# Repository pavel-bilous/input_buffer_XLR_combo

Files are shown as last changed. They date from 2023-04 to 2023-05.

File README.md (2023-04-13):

# Input buffer for amplifier with balanced inputs

This buffer serves as an impedance matching and is implemented on the board that allows for balanced XLR inputs for two channels.

## PCB rendered in 3d:
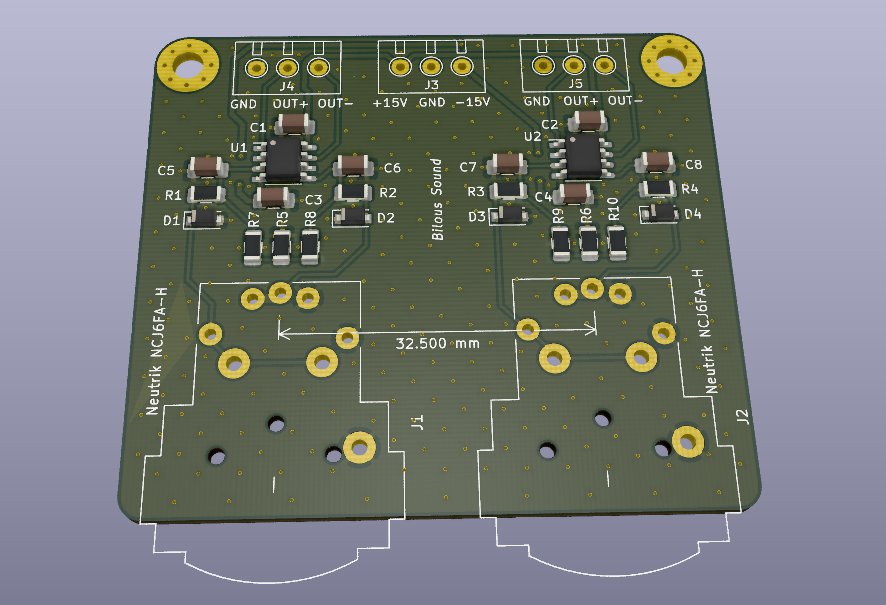
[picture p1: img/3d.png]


## Schematics:

Inputs are ESD protected with bidirectional TVS diodes. Not required, but nice to have. 

Opamps can be NE5532 or LM4562 or any other with good unity gain stability. 

Input XLR connectors are Neutrik NCJ6FA-H.

Capacitors for input low pass filters are C0G or NP0 type. Decoupling capacitors are X7R 100nF or higher (1uF - 10uF will work great).

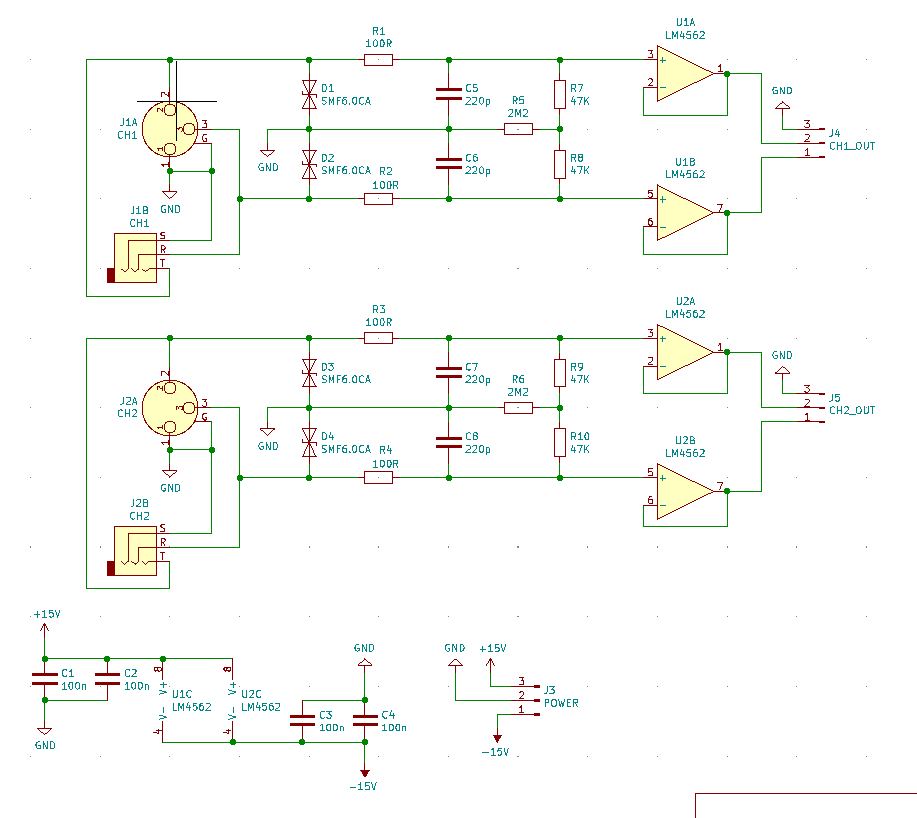
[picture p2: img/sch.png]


## PCB layout:

Bottom layer is GND. Top layer is signal + power and GND poured in between. Stiching vias are then applied to connect bottom and top GND planes to ensure those are as close to 0 as possible.

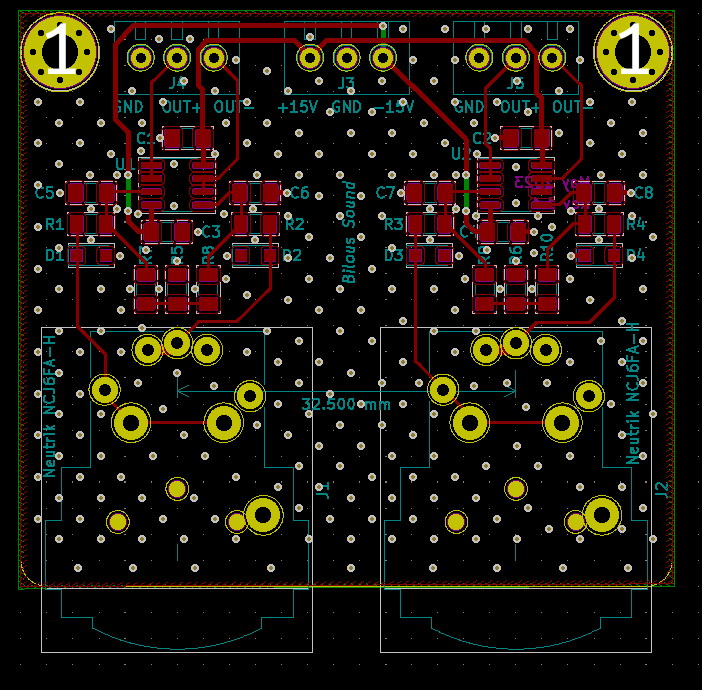
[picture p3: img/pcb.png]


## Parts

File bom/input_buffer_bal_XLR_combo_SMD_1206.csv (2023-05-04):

Id | Designator | Package | Quantity | Designation | Supplier and ref
1 | C8,C7,C6,C5 | C_1206_3216Metric_Pad1.42x1.75mm_HandSolder | 4 | 220p
2 | C4,C3,C2,C1 | C_1206_3216Metric_Pad1.42x1.75mm_HandSolder | 4 | 100n
3 | J1 | Jack_XLR-6.35mm_Neutrik_NCJ6FA-H-0_Horizontal | 1 | CH1
4 | J2 | Jack_XLR-6.35mm_Neutrik_NCJ6FA-H-0_Horizontal | 1 | CH2
5 | D4,D3,D2,D1 | D_SOD-123F | 4 | SMF6.0CA
6 | U2,U1 | SOIC-8_3.9x4.9mm_P1.27mm | 2 | LM4562
7 | R10,R9,R8,R7 | R_1206_3216Metric | 4 | 47K
8 | R6,R5 | R_1206_3216Metric | 2 | 2M2
9 | R4,R3,R2,R1 | R_1206_3216Metric | 4 | 100R
10 | H2,H1 | MountingHole_3.5mm_Pad_Via | 2 | MountingHole
11 | J5 | TerminalBlock_ Amphenol_01_03_P3.50mm | 1 | CH2_OUT
12 | J4 | TerminalBlock_ Amphenol_01_03_P3.50mm | 1 | CH1_OUT
13 | J3 | TerminalBlock_ Amphenol_01_03_P3.50mm | 1 | POWER

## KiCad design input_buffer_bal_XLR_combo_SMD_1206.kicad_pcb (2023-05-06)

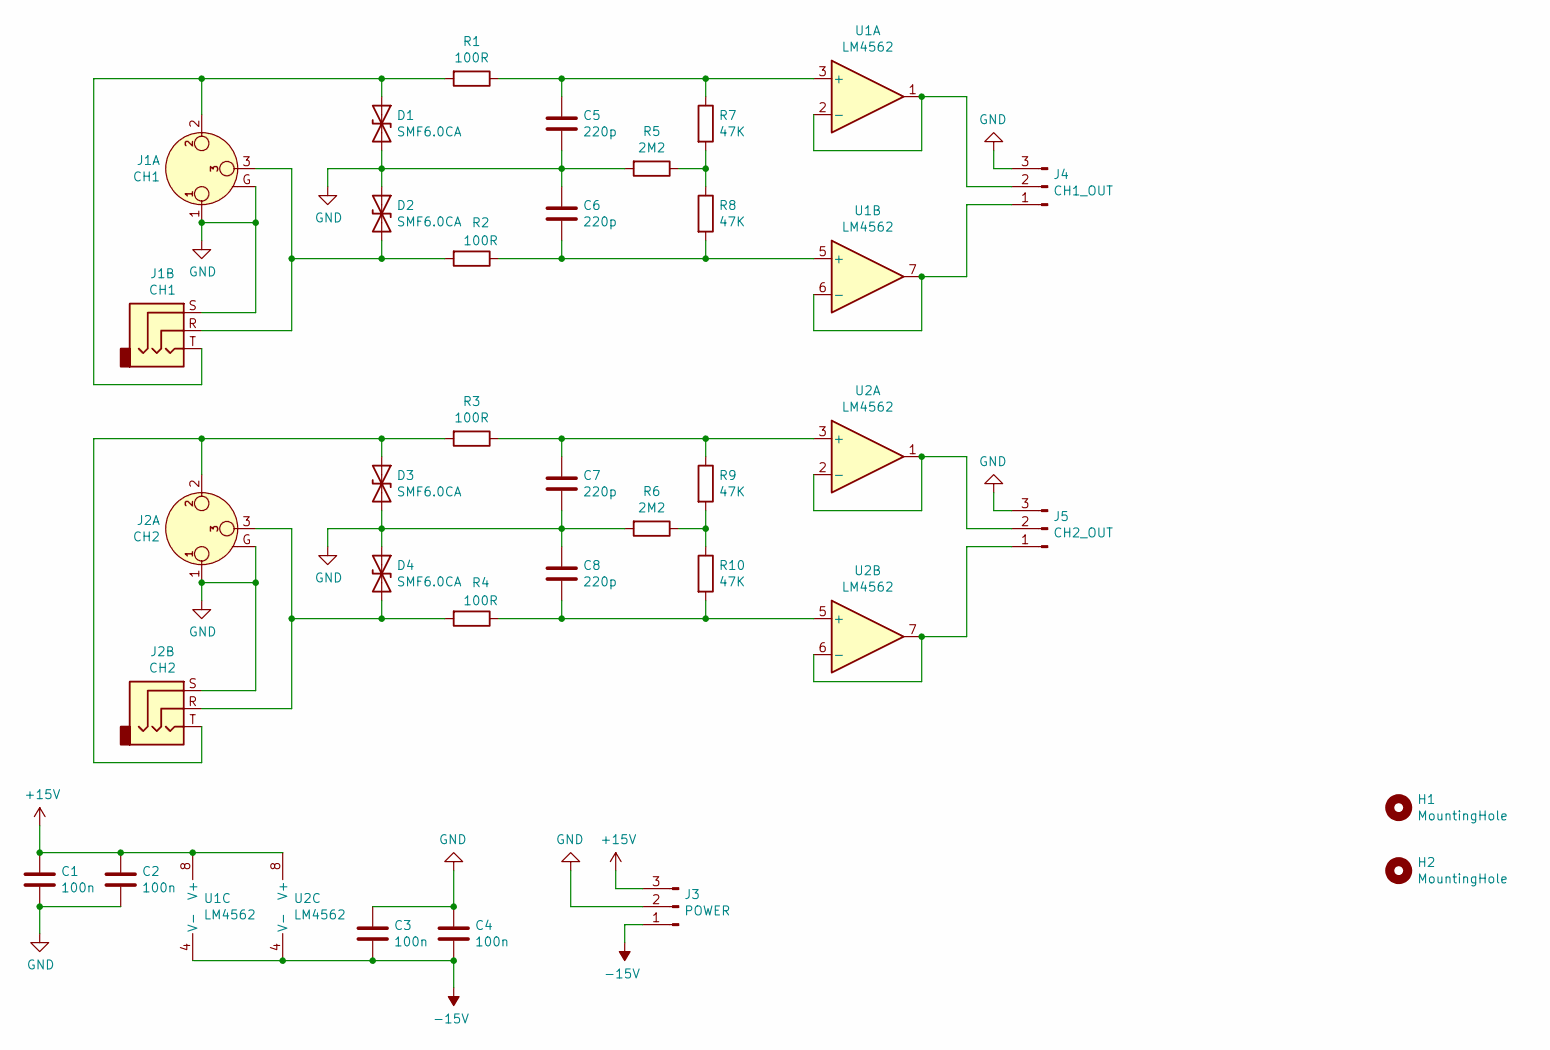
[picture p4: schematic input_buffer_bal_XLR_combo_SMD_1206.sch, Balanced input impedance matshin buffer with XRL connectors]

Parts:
C1, C2, C3, C4: 100n; C_1206_3216Metric_Pad1.42x1.75mm_HandSolder
C5, C6, C7, C8: 220p; C_1206_3216Metric_Pad1.42x1.75mm_HandSolder
D1, D2, D3, D4: SMF6.0CA; D_SOD-123F
H1, H2: MountingHole; MountingHole_3.5mm_Pad_Via
J1: CH1; Jack_XLR-6.35mm_Neutrik_NCJ6FA-H-0_Horizontal
J2: CH2; Jack_XLR-6.35mm_Neutrik_NCJ6FA-H-0_Horizontal
J3: POWER; TerminalBlock_ Amphenol_01_03_P3.50mm
J4: CH1_OUT; TerminalBlock_ Amphenol_01_03_P3.50mm
J5: CH2_OUT; TerminalBlock_ Amphenol_01_03_P3.50mm
R1, R2, R3, R4: 100R; R_1206_3216Metric
R5, R6: 2M2; R_1206_3216Metric
R7, R8, R9, R10: 47K; R_1206_3216Metric
U1, U2: LM4562; SOIC-8_3.9x4.9mm_P1.27mm

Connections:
+15V: C1.1, C2.1, J3.3, U1.8 (V+), U2.8 (V+)
-15V: C3.2, C4.2, J3.1, U1.4 (V-), U2.4 (V-)
GND: C1.2, C2.2, C3.1, C4.1, C5.2, C6.1, C7.2, C8.1, D1.2 (A2), D2.1 (A1), D3.2 (A2), D4.1 (A1), J1.1, J1.G, J1.S, J2.1, J2.G, J2.S, J3.2, J4.3, J5.3, R5.2, R6.2
unnamed: C5.1, R1.1, R7.1, U1.3 (+)
unnamed: C6.2, R2.1, R8.2, U1.5 (+)
unnamed: C7.1, R3.1, R9.1, U2.3 (+)
unnamed: C8.2, R4.1, R10.2, U2.5 (+)
unnamed: D1.1 (A1), J1.2, J1.T, R1.2
unnamed: D2.2 (A2), J1.3, J1.R, R2.2
unnamed: D3.1 (A1), J2.2, J2.T, R3.2
unnamed: D4.2 (A2), J2.3, J2.R, R4.2
unnamed: J4.1, U1.6 (-), U1.7
unnamed: J4.2, U1.1, U1.2 (-)
unnamed: J5.1, U2.6 (-), U2.7
unnamed: J5.2, U2.1, U2.2 (-)
unnamed: R5.1, R7.2, R8.1
unnamed: R6.1, R9.2, R10.1

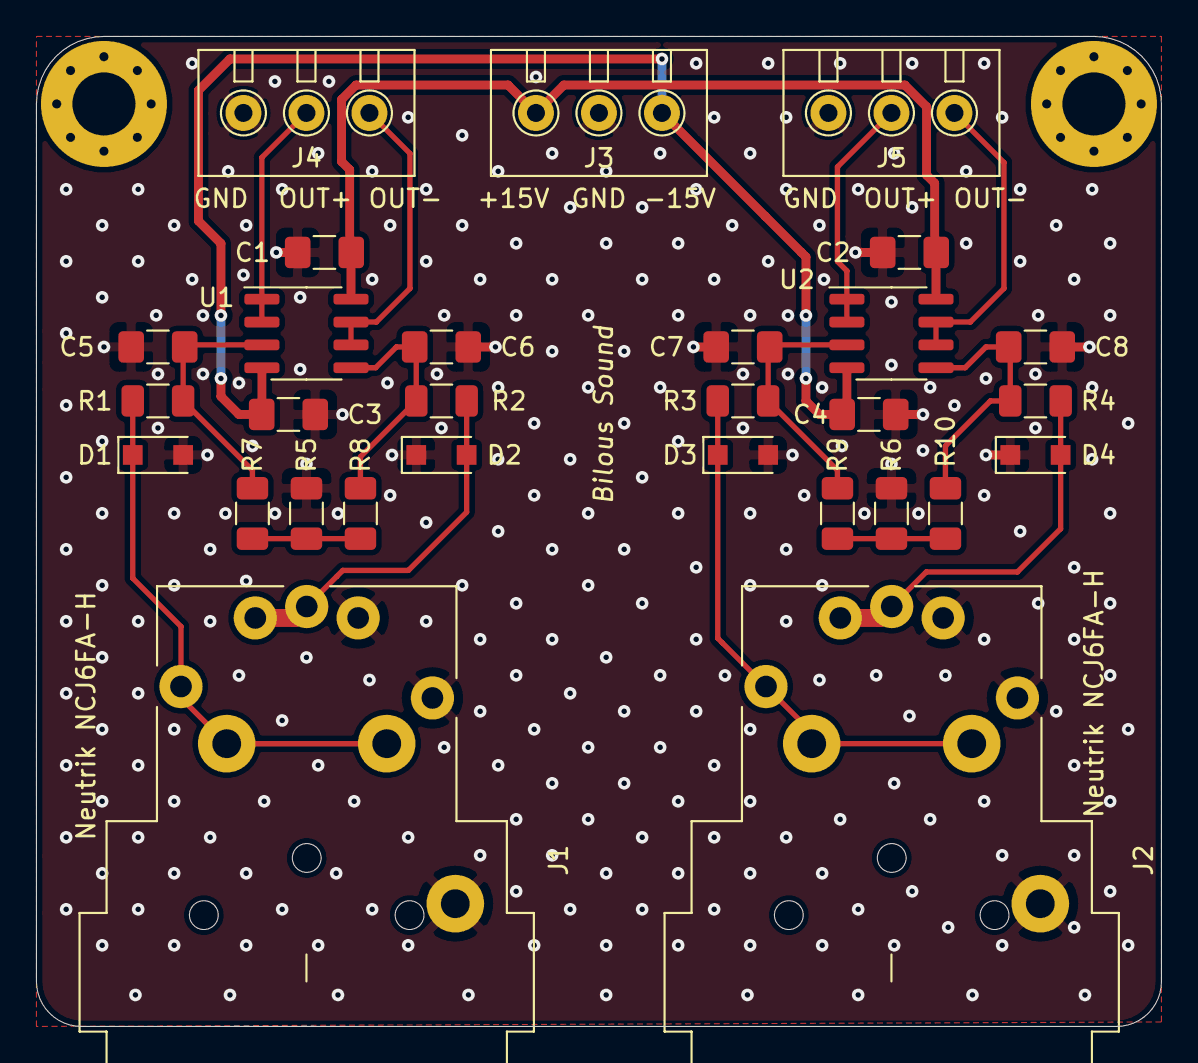
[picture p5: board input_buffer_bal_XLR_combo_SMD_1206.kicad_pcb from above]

Board: 2 copper layers, 62.5 x 55.0 mm, 31 parts (0 on the bottom side), 17 nets.

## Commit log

2023-04-13 generated gerbers
    [input_buffer_bal_XLR_SMD_1206-B_Cu.gbr, input_buffer_bal_XLR_SMD_1206-B_Mask.gbr, input_buffer_bal_XLR_SMD_1206-B_Paste.gbr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]
2023-05-04 minor improvements
    [input_buffer_bal_XLR_combo_SMD_1206.kicad_pcb, input_buffer_bal_XLR_combo_SMD_1206.sch]
2023-05-05 minor fixes
    [input_buffer_bal_XLR_combo_SMD_1206.kicad_pcb]
